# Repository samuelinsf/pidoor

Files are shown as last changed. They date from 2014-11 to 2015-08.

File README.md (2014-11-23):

pidoor
---------
A low cost, reliable, hacker friendly keycard and door-open monitoring system written
in python for the Raspberry Pi.

Features:
--------------
- Uses low cost weigand rfid reader and keyfobs.
- Simple.
- Alarm system style DC loops for door open/closed monitoring.
- Phone friendly web based activity viewer (quickly answers: did I leave the garage door open?)

In continuous use since late 2013.

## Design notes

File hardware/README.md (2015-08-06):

Hardware
--------------
The circuit for the cardreader interface is used twice.
The isolated pulldown to ground scheme also works to
control the cardreader's led and buzzer,
but I didn't need those, and so have left them out.
![ alt Weigand ttl to pi interface schematic] (cardreader-interface.png)

There is one of the loop isolation circuits for each
of the classic style burglar alarm DC loops I have tracked.
The current installation has 5 of them running.
![ alt 12v alarm loop isolation interface for pi ] (loop-sense-isolated.png)

The LED in the relay control circuit is a backemf quench.
Any diode will do.
![ alt door buzzer relay interface for pi ] (solenoid-control-schematic.png)

Some key parts
------------
The PS2502-4-A is 4 pack of optocouplers.
It is nice because it works great with the Pi's 3.3v gpio,
with the 5v TTL of the Weigand card reader, and can drive the 12v relays.
[http://www.mouser.com/ProductDetail/CEL/PS2502-4-A/?qs=ZyqMiHkgYmNQKZ3ZxC9WTg%3D%3D](http://www.mouser.com/ProductDetail/CEL/PS2502-4-A/?qs=ZyqMiHkgYmNQKZ3ZxC9WTg%3D%3D)

For the magnetic switch, I used:
[http://www.adafruit.com/products/375?gclid=CITIyu2Wj8ICFVJgfgodyTIA6w](http://www.adafruit.com/products/375?gclid=CITIyu2Wj8ICFVJgfgodyTIA6w)

For the card reader I used this nifty low cost 125khz rfid weigand26 reader:
[http://www.dx.com/p/mini-door-access-card-reader-black-116855#.VHEE7ofJ-2w](http://www.dx.com/p/mini-door-access-card-reader-black-116855#.VHEE7ofJ-2w)
Interestingly, my 2003 Honda cardkey also scans with this system.

For keyfobs I use these:
[http://www.dx.com/p/mjid-1-entrance-guard-inductive-id-key-card-blue-10-pcs-224560#.VHEFJofJ-2w](http://www.dx.com/p/mjid-1-entrance-guard-inductive-id-key-card-blue-10-pcs-224560#.VHEFJofJ-2w)

For the solenoid control relay I used:
[http://www.dx.com/p/mini-5-pin-10a-power-relay-for-security-system-black-5-pack-129859#.VHEGJIfJ-2w](http://www.dx.com/p/mini-5-pin-10a-power-relay-for-security-system-black-5-pack-129859#.VHEGJIfJ-2w)

To make everything nice I put all the parts in an alarm system box:
[http://www.amazon.com/Interlogix-NetworX-X-Pand-A-Can-Enclosure-NX-003/dp/B00171A43Y](http://www.amazon.com/Interlogix-NetworX-X-Pand-A-Can-Enclosure-NX-003/dp/B00171A43Y)

To make it robust I soldered everything down onto one of these (with a temperature controlled weller):
[http://www.adafruit.com/products/1135](http://www.adafruit.com/products/1135)

Because I live in San Francisco my house already had an
entry gate with built in latch solenoid.

For the raspberry Pi I used a model B.

For storing the logs and access database I use a USB thumb drive
mounted in sync mode... I switched to this model after the random
one I was using began to get slow:
[http://www.amazon.com/gp/product/B00KT7DXIU](http://www.amazon.com/gp/product/B00KT7DXIU)

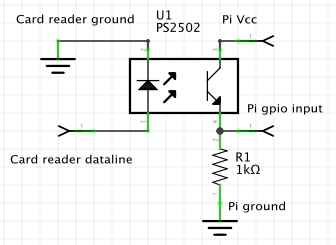
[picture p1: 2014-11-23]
hardware/cardreader-interface.png

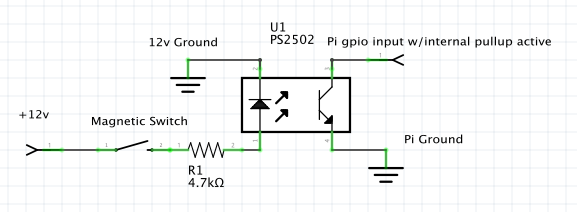
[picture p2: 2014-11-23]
hardware/loop-sense-isolated.png

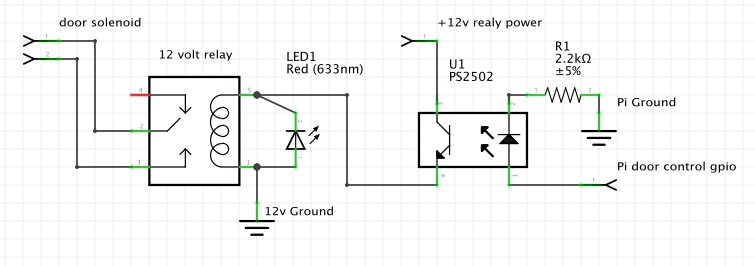
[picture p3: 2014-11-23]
hardware/solenoid-control-schematic.png

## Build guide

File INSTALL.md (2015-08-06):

Installation                                                                                                                                                             
---------------                                                                                                                                                          
Build and connect some hardware (see hardware/)                                                                                                                        

Software side
-------------------
Install lazytable

    pip install lazytable

Copy this repo to /root on the pi.
Add a readwrite mount /data I put it on a thumb drive formatted like so:

    mkfs.ext4 -L DATA /dev/sda1 

With it like this in /etc/fstab:

    LABEL="DATA" /data              ext4    defaults,noatime,sync,nofail  0       2

Install daemontools:

    apt-get install daemontools daemontools-run                                                                                                                          

Make /etc/service a link to /data/service

    mv /etc/service /etc/service.dist
    ln -s /data/service /etc/service

Here is an example service file for door.py:

    mkdir -p /data/service/front_gate 
    cat > /data/service/front_gate/run <<EOF
    #!/bin/bash  
    export PATH=/usr/local/sbin:/usr/local/bin:/usr/sbin:/usr/bin:/sbin:/bin 
    cd /root                                                                                                                                                             
    exec 2>&1                                                                                                                                                            
    exec ./door.py --data-dir /data --name front_gate --d0 17 --d1 18 --relay 4
    EOF

door.py uses an access card database which you can edit using card.py

For example, to setup a card with number 1234567:

    ./card.py 1234567 front_gate 1 sam

To see a list of cards and status, run card with no arguments.

    ./card.py

loop.py monitors a DC loop attached to a gpio:

    mkdir -p /data/service/hall_door_loop
    cat > /data/service/hall_door_loop/run <<EOF
    #!/bin/bash
    export PATH=/usr/local/sbin:/usr/local/bin:/usr/sbin:/usr/bin:/sbin:/bin

    cd /root
    exec 2>&1
    exec ./loop.py --data-dir /data --name hall_door_loop --gpio 24
    EOF

web_ui.py needs some additional configuration, see the
beginning of web_ui.py for an example ini

    mkdir -p /data/service/web_ui
    cat > /data/service/web_ui/run <<EOF
    #!/bin/bash
    export PATH=/usr/local/sbin:/usr/local/bin:/usr/sbin:/usr/bin:/sbin:/bin

    cd /root
    exec > /dev/null
    exec 2>&1
    exec ./web_ui.py /data/web_ui.ini
    EOF

For robustness I made the Pi readonly root and gave it a static IP.
[https://wiki.debian.org/ReadonlyRoot](https://wiki.debian.org/ReadonlyRoot)

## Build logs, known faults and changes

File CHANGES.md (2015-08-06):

## 1.0

## Changes
* add changes file
* update to use lazytable 0.4.0

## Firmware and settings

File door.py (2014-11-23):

#!/usr/bin/python

import os
import os.path
import sys
import select
import optparse

import RPi.GPIO
import lazytable
import log


class Door():
    def __init__(self, d0, d1, relay):
        self.d0 = d0
        self.d1 = d1
        self.relay = relay
        self.fd={}
        self.relock_after = self._get_time()

    def _setup_input(self, chan, data_bit):
        gpio_d = '/sys/class/gpio/gpio%d' % chan
        if os.path.exists(gpio_d):
            open('/sys/class/gpio/unexport','wb').write('%d\n' % chan)
        open('/sys/class/gpio/export','wb').write('%d\n' % chan)
        RPi.GPIO.setmode(RPi.GPIO.BCM);
        RPi.GPIO.setup(chan, RPi.GPIO.IN, pull_up_down=RPi.GPIO.PUD_DOWN)
        #open(os.path.join(gpio_d, 'edge'), 'wb').write('falling\n')
        open(os.path.join(gpio_d, 'edge'), 'wb').write('falling\n')
        fd = os.open(os.path.join(gpio_d, 'value'), os.O_RDONLY)
        #print 'fd', chan, fd, os.read(fd, 1)
        self.fd[fd] = (self, data_bit)
        
    def _get_time(self):
        # we use the system uptime because the wall
        # time may jump around in the embeded system
        return float(open('/proc/uptime').read().split()[0])

    def setup_inputs(self):
        self._setup_input(self.d0, 0)
        self._setup_input(self.d1, 1)

    def setup_output(self):
        gpio_d = '/sys/class/gpio/gpio%d' % self.relay
        if os.path.exists(gpio_d):
            open('/sys/class/gpio/unexport','wb').write('%d\n' % self.relay)
        open('/sys/class/gpio/export','wb').write('%d\n' % self.relay)
        open(os.path.join(gpio_d, 'direction'), 'wb').write('low\n')

    def read_card(self):
        bitsread = 0
        value = 0
        timeout = .1
        #print  'fd keys', self.fd.keys()
        for fd in  self.fd.keys():
            os.lseek(fd,0,0)
            os.read(fd,1)
        (i, o, x) = select.select([], [], self.fd.keys(), timeout)
        while bitsread < 26:
            #print x
            if not x:
                # timeout
                break
            if len(x) > 1:
                # error
                print 'error'
                break
            value = (value << 1) + self.fd[x[0]][1]
            os.lseek(x[0],0,0)
            os.read(x[0],1)
            bitsread += 1
            (i, o, x) = select.select([], [], self.fd.keys(), timeout)
            #print bitsread, value
        value = value >> 1
        value = value & 0xffffff
        return value

    def open_door(self, seconds):
        gpio_d = '/sys/class/gpio/gpio%d' % self.relay
        self.relock_after = self._get_time() + seconds
        open(os.path.join(gpio_d, 'value'), 'wb').write('1\n')
        
    def maintain_door(self):
        max_open_seconds = 6
        gpio_d = '/sys/class/gpio/gpio%d' % self.relay
        now = self._get_time()
        if now > self.relock_after:
            open(os.path.join(gpio_d, 'value'), 'wb').write('0\n')

        if (self.relock_after - now ) > max_open_seconds:
            # timer wrap?
            # somehow its too far out in future to close door
            # just close door
            open(os.path.join(gpio_d, 'value'), 'wb').write('0\n')

def card_allowed(card, door, path):
    card_db = os.path.join(path, 'cards_db.sqlite')
    t = lazytable.open(card_db, 'cards')
    r = list(t.get({'card': card, 'door': door}))
    disposition = 'card_not_known'
    is_allowed = 0
    note = ''
    if r:
        is_allowed = r[0]['is_allowed']
        disposition = 'card_known'
        note = r[0]['note']

    log.log(door,
            {'is_allowed': is_allowed, 
            'disposition': disposition, 
            'card': card, 
            'door':door,
            'card_note':note
            }, path)
    return (is_allowed == 1)
            
def main():
    usage = """%prog --data-dir PATH --d0 N --d1 N --relay N --name NAME"""
    parser = optparse.OptionParser(usage)
    parser.add_option("--d0", dest="d0",
                      action="store", type="int", help="gpio pin for weigand d0")
    parser.add_option("--d1", dest="d1",
                      action="store", type="int", help="gpio pin for weigand d1")
    parser.add_option("--relay", dest="relay",
                      action="store", type="int", help="gpio pin for latch buzzer relay")
    parser.add_option("--name", dest="name",
                      action="store", help="door name ex: front_gate")
    parser.add_option("--data-dir", dest="data_dir",
                      action="store", help="path to dir with logs and carddb")

    (options, args) = parser.parse_args()

    data_dir = options.data_dir
    name = options.name
    d0 = options.d0
    d1 = options.d1
    relay = options.relay

    if not (data_dir and name and d0 and d1 and relay):
        parser.print_help()
        exit(2)

    d = Door(d0=d0, d1=d1, relay=relay)
    d.setup_output()
    d.setup_inputs()
    while True:
        v =  d.read_card()
        if v:
            #print 'got:', v
            if card_allowed(v, name, data_dir):
                d.open_door(1)
        d.maintain_door()

if __name__ == '__main__':
    main()

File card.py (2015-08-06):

#!/usr/bin/python

import lazytable
import sys
import os.path
import optparse

def dump(t):
    all = list(t.get({}))
    print '      card     door       is_allowed    note'
    print '====================================================='
    for c in all:
        print '%12d %12s %4d            %s' % (c['card'], c['door'], c['is_allowed'], c['note'])


def main():
    path = '/data'

    usage = """%prog [--data-dir PATH] [card door is_allowed note]"""
    parser = optparse.OptionParser(usage)
    parser.add_option("--data-dir", dest="data_dir", default=path,
                      action="store", help="path to dir with logs and carddb")
    (options, args) = parser.parse_args()

    card_db = os.path.join(options.data_dir, 'cards_db.sqlite')
    t = lazytable.open(card_db, 'cards')

    if len(args) == 4:
        # card door is_allowed note
        (card, door, is_allowed, note) = args
        new = {'card':int(card), 'door':door, 'is_allowed':int(is_allowed), 'note':note}
        t.upsert({'card':card, 'door':door}, new)
    else:
        dump(t)
        parser.print_usage()
        exit()

if __name__ == '__main__':
    main()
